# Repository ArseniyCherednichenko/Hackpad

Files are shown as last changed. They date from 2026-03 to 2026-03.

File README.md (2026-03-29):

# Arseniy's HackPad

My Hackpad is a 3×3 macro keypad, which can be programmed to address all needs. It runs on a Seeed XIAO RP2040, and features Cherry MX mechanical switches, SK6812 RGB LEDs, a rotary encoder, and an OLED status display.



## Why I built this

I wanted to have a custom keypad on my desk and use shortcuts assigned to each key to simplify and make my workflow more efficient.

---
<!--
## Pin Assignments
| Signal | XIAO Pin | Description |
|---|---|---|
| ROW0 | D0 | Switch matrix row 0 |
| ROW1 | D1 | Switch matrix row 1 |
| ROW2 | D2 | Switch matrix row 2 |
| COL0 | D3 | Switch matrix column 0 |
| COL1 | D6 | Switch matrix column 1 |
| COL2 | D7 | Switch matrix column 2 |
| OLED SDA | D4 | I²C data for SSD1306 display |
| OLED SCL | D5 | I²C clock for SSD1306 display |
| ENC_A | D8 | Rotary encoder channel A |
| ENC_B | D9 | Rotary encoder channel B |
| LED_DATA | D10 | SK6812 data chain |

---

-->
## Usage

To use Hackpad, order the PCB using `gerbers.zip` from JLCPCB, print the 3D enclosure, solder the components, install firmware and assemble everything. Edit `main.py` to customise your keymap.

## Schematic



---

## PCB 



---

## Files Layout

```
PCB/
  hackpad.kicad_pro     
  hackpad.kicad_sch
  hackpad.kicad_prl
  hackpad.kicad_pcb
  gerbers.zip    
CAD/
  Hackpad Keyboard Outline.step
  Hackpad PCB.step
  Hackpad case BOTTOM.step
  Hackpad case TOP.step
  Hackpad case FULL.step
Firmware/
  main.py               
images/
  (screenshots)
BOM.csv
README.md
```

---

## PCB Fabrication Notes

- Board size: **80 × 70 mm**, 2 layers, 1.6 mm FR4
- Min trace width: 0.2 mm (signal), 0.5 mm (power)
- Min via: 0.8 mm drill, 0.4 mm annular ring
- Surface finish: HASL or ENIG

---

## Case Printing Notes

- Print `Hackpad case TOP.step`, `Hackpad case BOTTOM.step` and `Hackpad Keyboard Outline.step` in PLA or PETG, 0.2 mm layer height, 3–4 perimeters.
- Insert M3 heat-set inserts into the four corner bosses of the bottom tray using a soldering iron.
- PCB sits on the 2 mm standoffs inside the tray.
- Top plate secures with 4× M3×8 screws through the corner holes.
  
---

## Bill of Materials

| # | Component | Qty | Package | Supplier | Link | Price (€) |
|---|---|-----|---|---|---|---|
| 1 | Seeed XIAO RP2040 | 1 | DIP-14 (castellated) | AliExpress | [Buy](https://de.aliexpress.com/item/1005008200917480.html) | 5.49 |
| 2 | Cherry MX Compatible Switch | 9 | MX Hotswap 1U | Amazon | [Buy](https://www.amazon.de/Topiky-Mechanische-Tastaturschalter-Keyboard-Mounted-default/dp/B086MQXQW7) | 7.23 |
| 3 | SK6812 MINI-E RGB LED | 9 | Reverse-mount 3228 | AliExpress | [Buy](https://de.aliexpress.com/item/1005008308801366.html) | 4.82 |
| 4 | 1N4148 Diode | 9 | DO-35 (THT) | AliExpress | [Buy](https://de.aliexpress.com/item/1005009372401863.html) | 1.49 |
| 5 | EC11 Rotary Encoder | 1 | Alps EC11E, vertical, 20mm | AliExpress | [Buy](https://de.aliexpress.com/item/1005008036285937.html) | 5.18 |
| 6 | 0.91" OLED Display (SSD1306) | 1 | 4-pin I2C, 128×32 | AliExpress | [Buy](https://de.aliexpress.com/item/1005010665352578.html) | 7.11 |
| 7 | Encoder Knob | 1 | 6mm D-shaft | AliExpress | [Buy](https://de.aliexpress.com/item/4000027546987.html) | 3.76 |
| 8 | MX Keycaps (1U) | 9 | MX stem compatible | AliExpress | [Buy](https://de.aliexpress.com/item/1005010020786682.html) | 8.20 |
| 9 | M2.5×6mm Screws | 4 | M2.5 pan head | Moddiy | [Buy](https://www.moddiy.com/products/1268/M2.5-x-6mm-Black-Screws-CM2.5x6x4.5.html) | 0.69 |
| 10 | M2.5×4mm Standoffs | 4 | M2.5 female-female | Amazon | [Buy](https://www.amazon.de/Standoff-Schraube-Computer-Motherboard-Weiblich/dp/B0CCQBQHJQ) | 7.28 |
| 11 | Rubber Feet (adhesive) | 4 | ~8mm diameter | AliExpress | [Buy](https://de.aliexpress.com/item/1005007854664253.html) | 3.83 |
| 12 | USB-C Cable | 1 | USB-C to USB-A/C | AliExpress | [Buy](https://de.aliexpress.com/item/1005004784212304.html) | 1.93 |
| | | | | | **TOTAL** | **€32.80** |

---

*Built with ❤️ by Arseniy*

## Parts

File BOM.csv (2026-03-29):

# | Component | Quantity | Package/Footprint | Supplier | Links | Price (€)
1 | Seeed XIAO RP2040 | 1 | DIP-14 (castellated) | AliExpress | https://de.aliexpress.com/item/1005008200917480.html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 | 5.49
2 | Cherry MX Compatible Switch | 9 | MX Hotswap 1U | Amazon | https://www.amazon.de/Topiky-Mechanische-Tastaturschalter-Keyboard-Mounted-default/dp/B086MQXQW7 | 7.23
3 | SK6812 MINI-E RGB LED | 9 | Reverse-mount 3228 | AliExpress | https://de.aliexpress.com/item/1005008308801366.html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 | 4.82
4 | 1N4148 Diode | 9 | DO-35 (THT) | AliExpress | https://de.aliexpress.com/item/1005009372401863.html?isdl=y&src=shoparizeDE | 1.49
5 | EC11 Rotary Encoder | 1 | Alps EC11E, vertical, 20mm shaft | AliExpress | https://de.aliexpress.com/item/1005008036285937.html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 | 5.18
6 | 0.91" OLED Display (SSD1306) | 1 | 4-pin I2C header, 128×32 | AliExpress | https://de.aliexpress.com/item/1005010665352578.html?isdl=y&src=shoparizeDE | 7.11
7 | Encoder Knob | 1 | 6mm D-shaft compatible | AliExpress | https://de.aliexpress.com/item/4000027546987.html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 | 3.76
8 | MX Keycaps (1U) | 9 | MX stem compatible | AliExpress | https://de.aliexpress.com/item/1005010020786682.html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 | 8.2
9 | M2.5×6mm Screws | 4 | M2.5 pan head | Moddiy | https://www.moddiy.com/products/1268/M2.5-x-6mm-Black-Screws-CM2.5x6x4.5.html | 0.69
10 | M2.5×4mm Standoffs | 4 | M2.5 female-female | Amazon | https://www.amazon.de/Standoff-Schraube-Computer-Motherboard-Weiblich/dp/B0CCQBQHJQ?th=1 | 7.28
11 | Rubber Feet (adhesive) | 4 | ~8mm diameter | AliExpress | https://de.aliexpress.com/item/1005007854664253.html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 | 3.83
12 | USB-C Cable | 1 | USB-C to USB-A/C | AliExpress | https://de.aliexpress.com/item/1005004784212304.html?isdl=y&src=shoparizeDE | 1.93
 |  |  |  |  | TOTAL: | 32.8

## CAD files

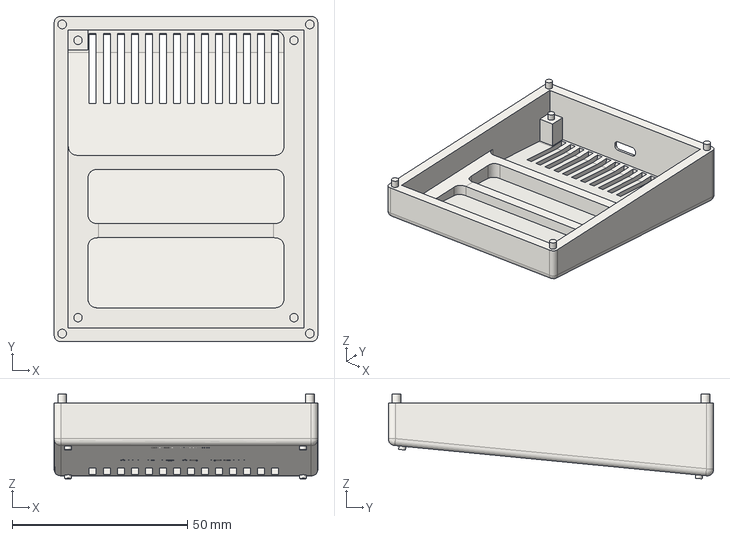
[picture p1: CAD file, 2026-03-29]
CAD/Hackpad case BOTTOM.step
75.2 x 92.7 x 24.2 mm

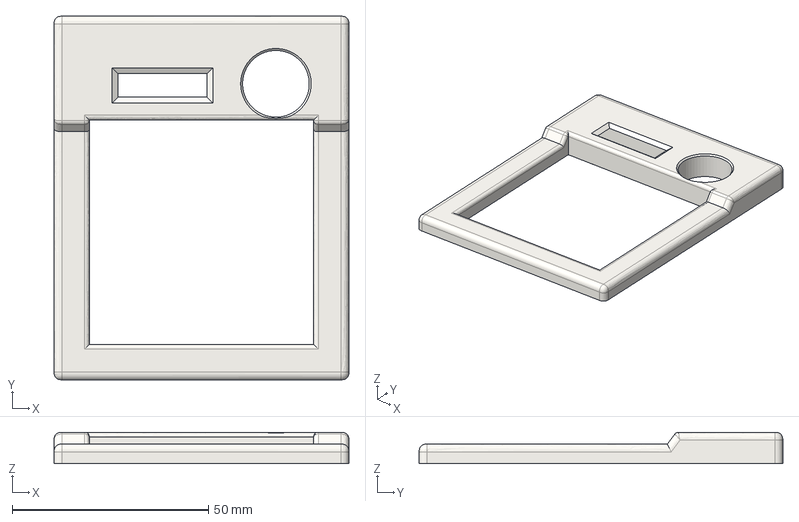
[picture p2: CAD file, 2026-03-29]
CAD/Hackpad case TOP.step
75.2 x 92.7 x 8.00 mm

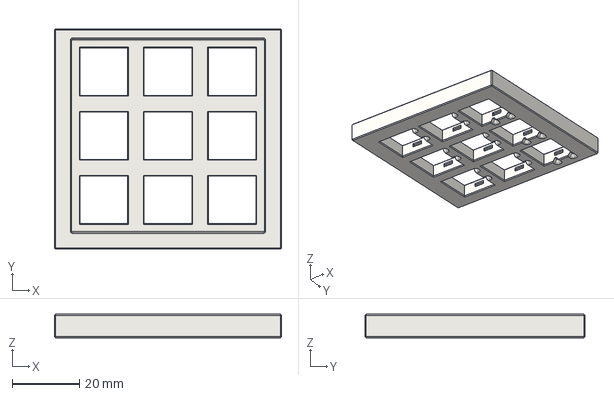
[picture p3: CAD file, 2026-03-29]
CAD/Hackpad Keyboard Outline.step
67.4 x 65.4 x 7.00 mm

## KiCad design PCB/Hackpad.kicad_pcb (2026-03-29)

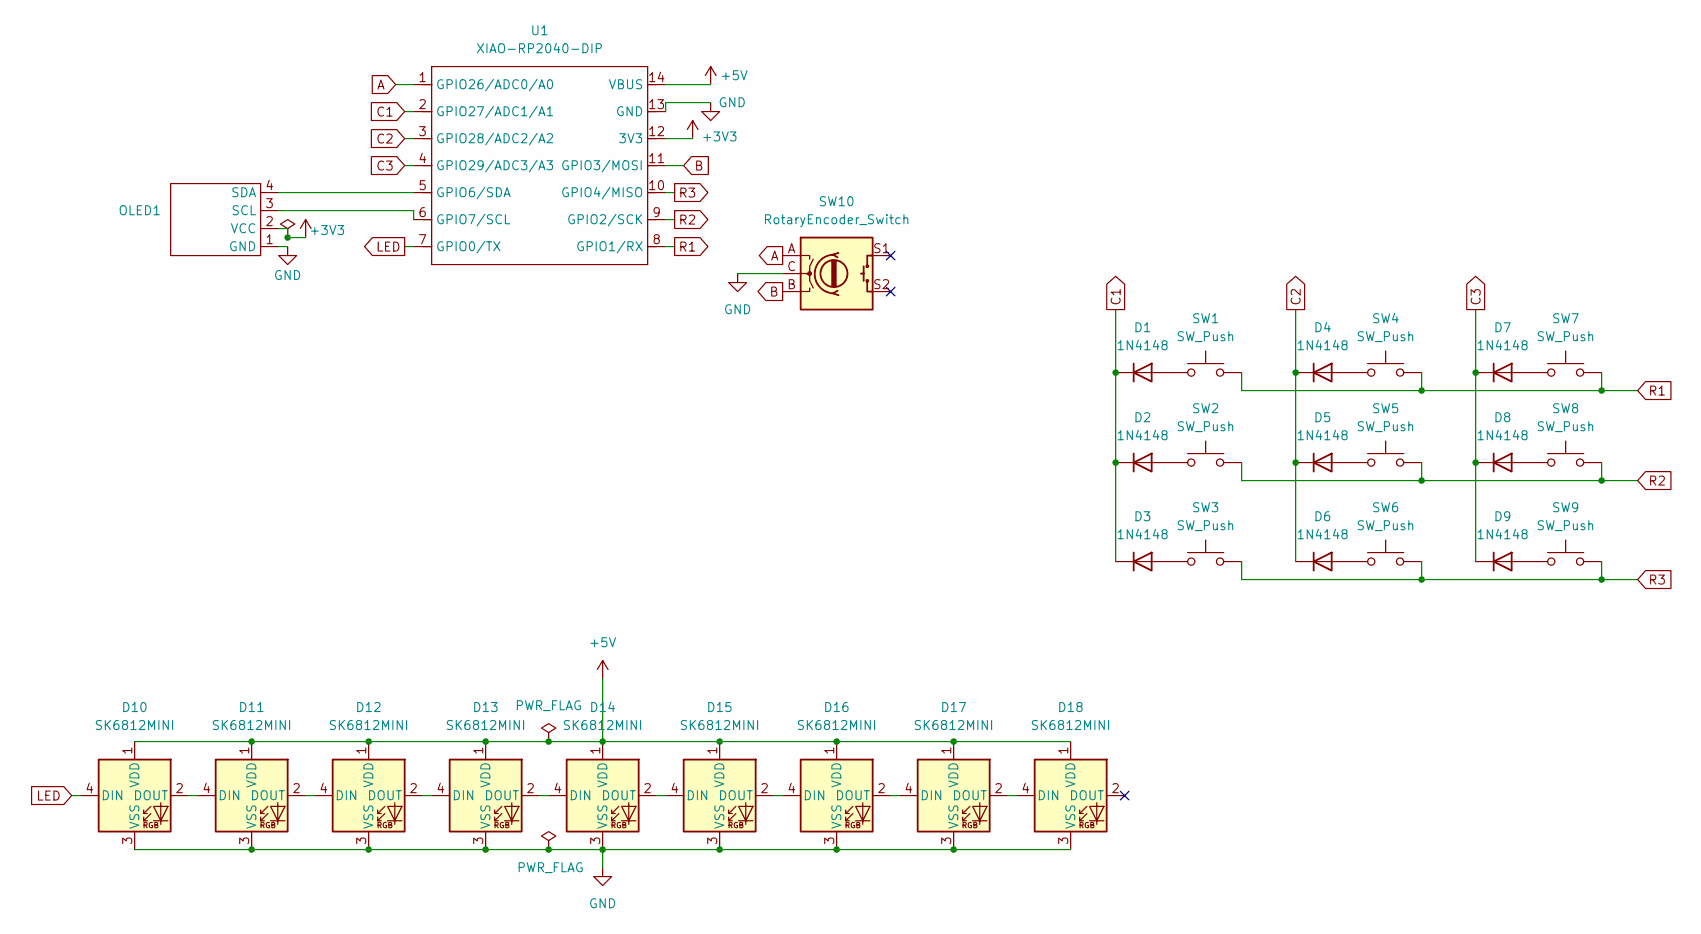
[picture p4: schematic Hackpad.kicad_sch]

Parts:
D1, D2, D3, D4, D5, D6, D7, D8, D9: 1N4148; D_DO-35_SOD27_P7.62mm_Horizontal
D10, D11, D12, D13, D14, D15, D16, D17, D18: SK6812MINI; MX_SK6812MINI-E_REV
OLED1: SSD1306-0.91-OLED-4pin-128x32
SW1, SW2, SW3, SW4, SW5, SW6, SW7, SW8, SW9: SW_Push; MX-Hotswap-1U
SW10: RotaryEncoder_Switch; RotaryEncoder_Alps_EC11E-Switch_Vertical_H20mm
U1: XIAO-RP2040-DIP

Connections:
+3V3: OLED1.2 (VCC), U1.12 (3V3)
+5V: D10.1 (VDD), D11.1 (VDD), D12.1 (VDD), D13.1 (VDD), D14.1 (VDD), D15.1 (VDD), D16.1 (VDD), D17.1 (VDD), D18.1 (VDD), U1.14 (VBUS)
A: SW10.A, U1.1 (GPIO26/ADC0/A0)
B: SW10.B, U1.11 (GPIO3/MOSI)
C1: D1.1 (K), D2.1 (K), D3.1 (K), U1.2 (GPIO27/ADC1/A1)
C2: D4.1 (K), D5.1 (K), D6.1 (K), U1.3 (GPIO28/ADC2/A2)
C3: D7.1 (K), D8.1 (K), D9.1 (K), U1.4 (GPIO29/ADC3/A3)
GND: D10.3 (VSS), D11.3 (VSS), D12.3 (VSS), D13.3 (VSS), D14.3 (VSS), D15.3 (VSS), D16.3 (VSS), D17.3 (VSS), D18.3 (VSS), OLED1.1 (GND), SW10.C, U1.13 (GND)
LED: D10.4 (DIN), U1.7 (GPIO0/TX)
unnamed: D1.2 (A), SW1.2
unnamed: D2.2 (A), SW2.2
unnamed: D3.2 (A), SW3.2
unnamed: D4.2 (A), SW4.2
unnamed: D5.2 (A), SW5.2
unnamed: D6.2 (A), SW6.2
unnamed: D7.2 (A), SW7.2
unnamed: D8.2 (A), SW8.2
unnamed: D9.2 (A), SW9.2
unnamed: D10.2 (DOUT), D11.4 (DIN)
unnamed: D11.2 (DOUT), D12.4 (DIN)
unnamed: D12.2 (DOUT), D13.4 (DIN)
unnamed: D13.2 (DOUT), D14.4 (DIN)
unnamed: D14.2 (DOUT), D15.4 (DIN)
unnamed: D15.2 (DOUT), D16.4 (DIN)
unnamed: D16.2 (DOUT), D17.4 (DIN)
unnamed: D17.2 (DOUT), D18.4 (DIN)
unnamed: OLED1.3 (SCL), U1.6 (GPIO7/SCL)
unnamed: OLED1.4 (SDA), U1.5 (GPIO6/SDA)
R1: SW1.1, SW4.1, SW7.1, U1.8 (GPIO1/RX)
R2: SW2.1, SW5.1, SW8.1, U1.9 (GPIO2/SCK)
R3: SW3.1, SW6.1, SW9.1, U1.10 (GPIO4/MISO)

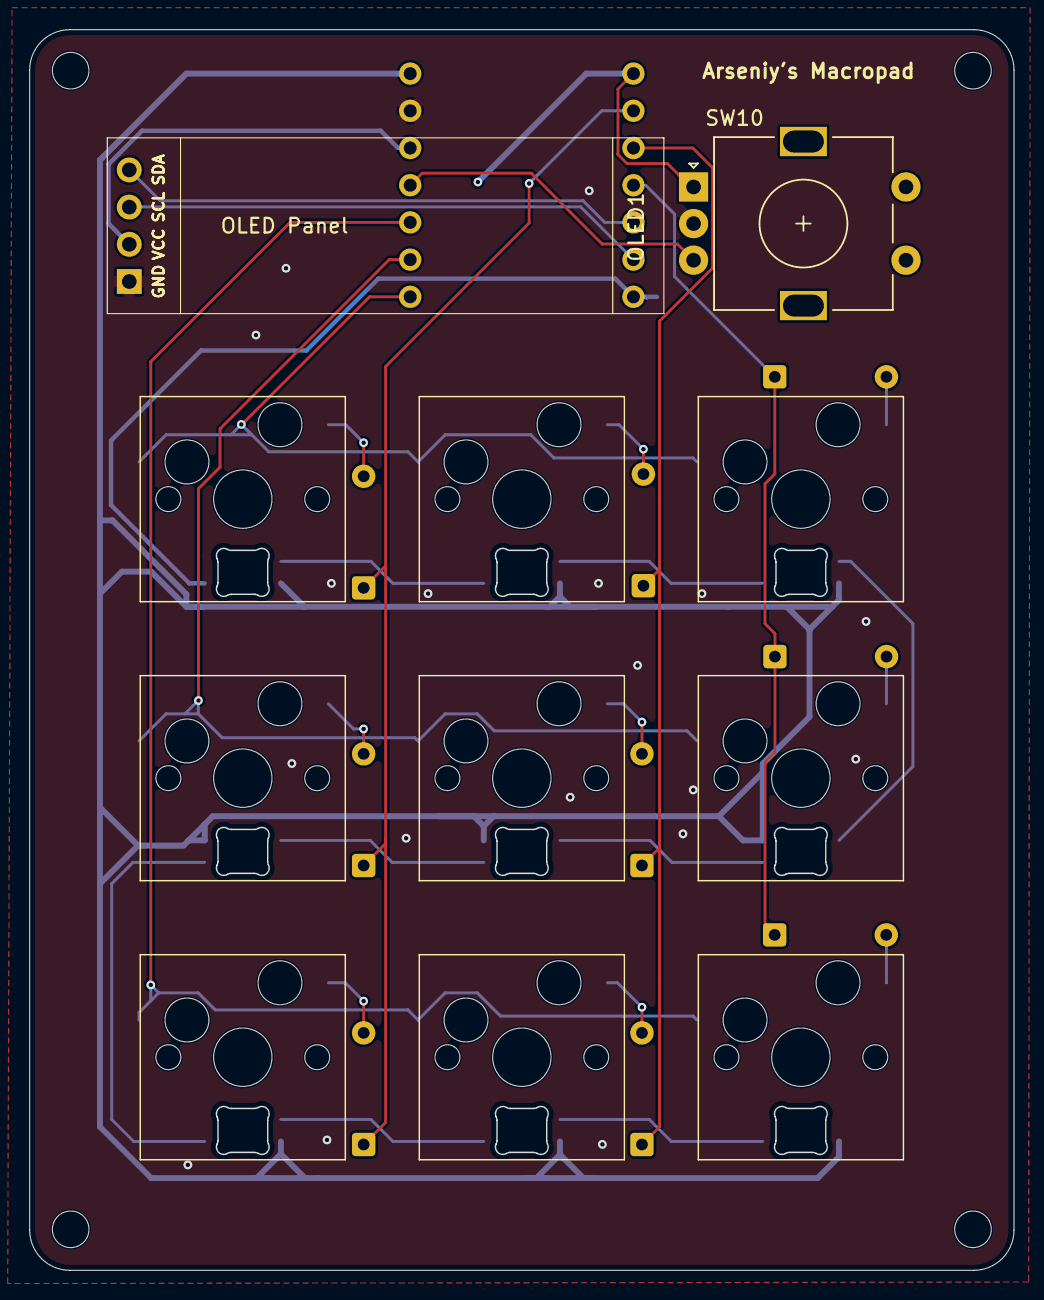
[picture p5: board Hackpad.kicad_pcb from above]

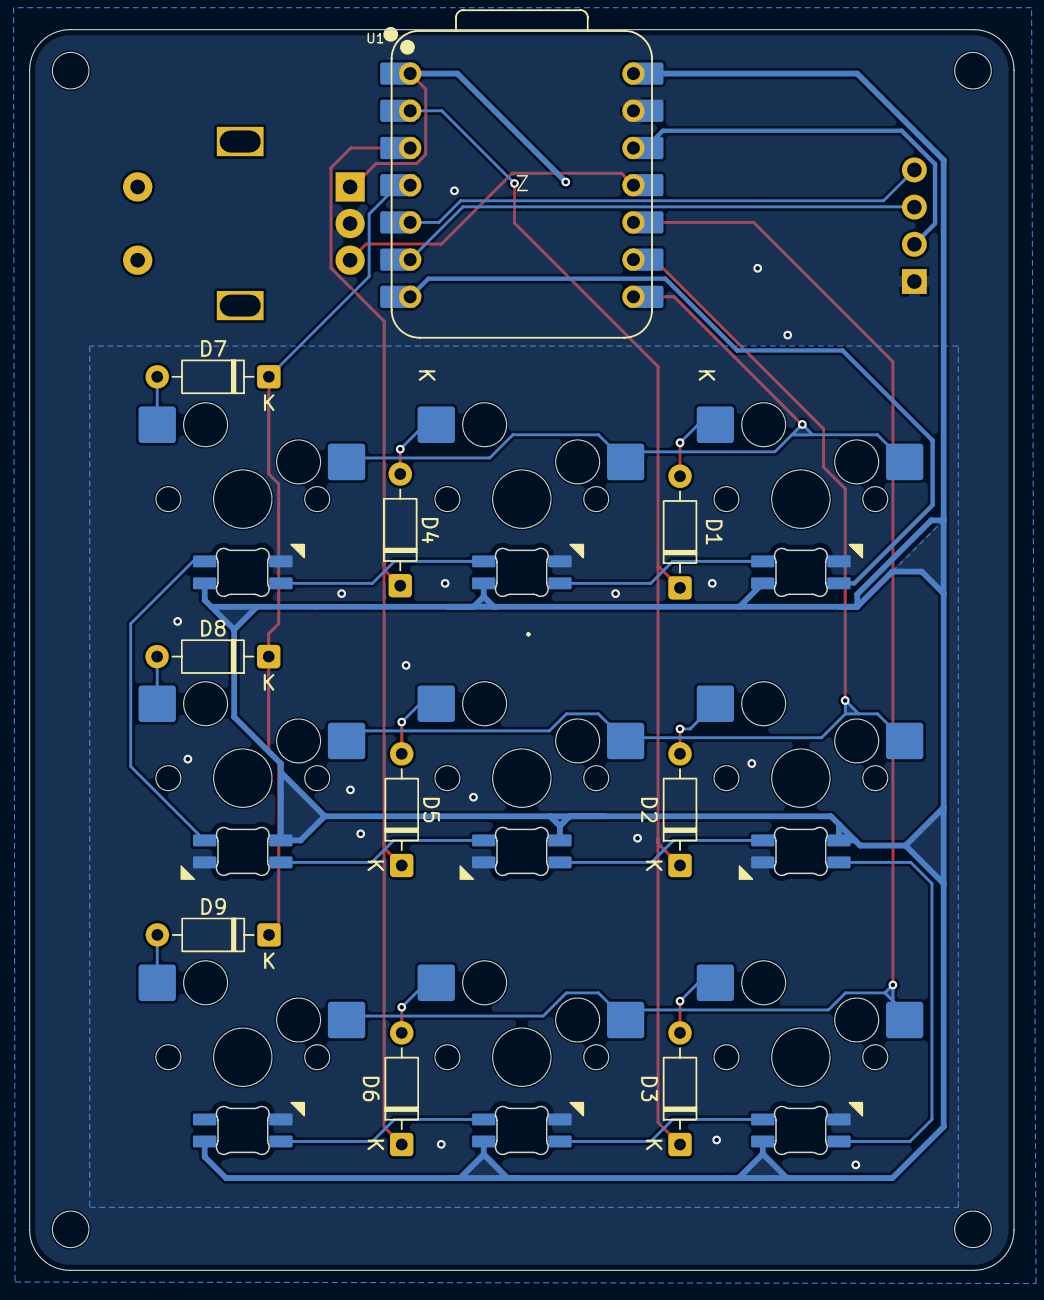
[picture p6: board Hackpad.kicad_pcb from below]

Board: 2 copper layers, 67.2 x 84.7 mm, 30 parts (19 on the bottom side), 31 nets.

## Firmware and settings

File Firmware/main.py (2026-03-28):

"""
HackPad — KMK firmware for Seeed XIAO RP2040
3×3 macro keypad + EC11 rotary encoder + SK6812 RGB LEDs + SSD1306 OLED

Hardware wiring
---------------
  D0  = Row 0            D6  = Col 1
  D1  = Row 1            D7  = Col 2
  D2  = Row 2            D8  = Encoder A
  D3  = Col 0            D9  = Encoder B  (encoder click not wired)
  D4  = OLED SDA         D10 = SK6812 data chain
  D5  = OLED SCL
  3V3 = OLED VCC / LED VDD
  GND = common ground

Switch matrix: COL2ROW, 1N4148 diode per switch
  Anode → row   Cathode → column
"""

import board
import busio
import supervisor

from kmk.kmk_keyboard import KMKKeyboard
from kmk.keys import KC
from kmk.scanners import DiodeOrientation
from kmk.modules.encoder import EncoderHandler
from kmk.extensions.rgb import RGB, AnimationModes
from kmk.extensions.display import Display, TextEntry, ImageEntry
from kmk.extensions.display.ssd1306 import SSD1306Driver
from kmk.modules.layers import Layers

# ── Keyboard object ────────────────────────────────────────────────────────────
keyboard = KMKKeyboard()

# ── Matrix ────────────────────────────────────────────────────────────────────
keyboard.col_pins   = (board.D3, board.D6, board.D7)          # COL0, COL1, COL2
keyboard.row_pins   = (board.D0, board.D1, board.D2)          # ROW0, ROW1, ROW2
keyboard.diode_orientation = DiodeOrientation.COL2ROW

# ── Layers module ─────────────────────────────────────────────────────────────
layers_mod = Layers()
keyboard.modules.append(layers_mod)

# ── RGB LEDs (SK6812 on D10, 9 pixels) ────────────────────────────────────────
rgb = RGB(
    pixel_pin   = board.D10,
    num_pixels  = 9,
    hue_default = 0,
    sat_default = 255,
    val_default = 50,
    animation_mode   = AnimationModes.BREATHING,
    animation_speed  = 1,
    breathe_center   = 1.5,
    knight_effect_length = 3,
)
keyboard.extensions.append(rgb)

# ── OLED Display (SSD1306, 128×32, I2C on D4=SDA / D5=SCL) ──────────────────
i2c_bus = busio.I2C(scl=board.D5, sda=board.D4)

oled_driver = SSD1306Driver(i2c=i2c_bus, device_address=0x3C)
display = Display(
    display     = oled_driver,
    width       = 128,
    height      = 32,
    flip        = False,
    flip_left   = False,
    flip_right  = False,
    brightness  = 1.0,
    brightness_step = 0.1,
    entries     = [
        TextEntry(text='HackPad', x=0, y=0,  x_anchor='L', y_anchor='T', inverted=False),
        TextEntry(text='Layer: ', x=0, y=16, x_anchor='L', y_anchor='T'),
        # Dynamic layer name — updated in on_runtime_enable callback below
    ],
)
keyboard.extensions.append(display)

# ── Encoder ───────────────────────────────────────────────────────────────────
encoder_handler = EncoderHandler()
encoder_handler.pins = ((board.D8, board.D9, None, False),)   # A, B, btn=None, reverse=False
keyboard.modules.append(encoder_handler)

# ── Key map ───────────────────────────────────────────────────────────────────
# 9 switches, 2 layers
#
# Physical layout (looking down at the keypad):
#   SW1  SW2  SW3      →  row 0, cols 0-2
#   SW4  SW5  SW6      →  row 1, cols 0-2
#   SW7  SW8  SW9      →  row 2, cols 0-2  (SW9 = MO(1) hold)
#
# Layer 0 — Media / macro layer
#   [Prev]   [Play]   [Next]
#   [VolDn]  [Mute]   [VolUp]
#   [Copy]   [Paste]  [MO(1)]     ← hold SW9 to activate layer 1
#   Encoder CW = Volume Up, CCW = Volume Down
#
# Layer 1 — RGB control layer
#   [Hue-] [Hue+]  [Sat-]
#   [Sat+] [Brt-]  [Brt+]
#   [Anim] [TOG ]  [TRNS]
#   Encoder CW = Hue+, CCW = Hue-

keyboard.keymap = [
    # ── Layer 0 ──────────────────────────────────────────────────────────────
    [
        KC.MPRV,  KC.MPLY,  KC.MNXT,
        KC.VOLD,  KC.MUTE,  KC.VOLU,
        KC.COPY,  KC.PASTE, KC.MO(1),
    ],
    # ── Layer 1 ──────────────────────────────────────────────────────────────
    [
        KC.RGB_HUD, KC.RGB_HUI, KC.RGB_SAD,
        KC.RGB_SAI, KC.RGB_VAD, KC.RGB_VAI,
        KC.RGB_ANI, KC.RGB_TOG, KC.TRNS,
    ],
]

# ── Encoder key bindings ──────────────────────────────────────────────────────
# encoder_handler.map format: list-of-layers, each layer is a tuple per encoder:
#   (counter_clockwise_key, clockwise_key)
encoder_handler.map = [
    # Layer 0: volume
    ((KC.VOLD, KC.VOLU),),
    # Layer 1: hue
    ((KC.RGB_HUD, KC.RGB_HUI),),
]

# ── Display layer name helper ─────────────────────────────────────────────────
LAYER_NAMES = {
    0: "Media",
    1: "RGB Ctrl",
}

# Simple runtime hook to update the layer name on the OLED
_last_layer = -1

def update_display():
    global _last_layer
    current = keyboard.active_layers[0] if keyboard.active_layers else 0
    if current != _last_layer:
        _last_layer = current
        name = LAYER_NAMES.get(current, f"Lyr {current}")
        display.entries[1] = TextEntry(
            text=f'Layer: {name}',
            x=0, y=16, x_anchor='L', y_anchor='T'
        )

# Attach hook — KMK calls this each matrix scan
keyboard._post_hid_hooks = [update_display]

# ── Go! ───────────────────────────────────────────────────────────────────────
if __name__ == '__main__':
    keyboard.go()

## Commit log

2026-03-29 Rename Screenshot 2026-03-29 at 20.05.30.png to CAD
2026-03-29 Rename Screenshot 2026-03-29 at 20.06.04.png to CAD back
2026-03-29 Rename Screenshot 2026-03-29 at 21.07.40.png to PCB
2026-03-29 Rename Screenshot 2026-03-29 at 21.07.59.png to Schematic
2026-03-29 Revise README for clarity and add new sections
    Updated the README to correct the wording from 'coded' to 'programmed' and added sections for Schematic and PCB with images. Expanded the Bill of Materials with detailed component listings and links.
2026-03-29 Revise README with project name and details
    Updated project name and enhanced description for clarity. Revised case printing notes and added detailed bill of materials.
